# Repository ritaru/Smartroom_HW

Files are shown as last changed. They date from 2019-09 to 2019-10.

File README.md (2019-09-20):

# ATmega256RFR2 Zigbee Board & Firmware

## Development board specs

- 50mm x 50mm 1.6T FR-4 1oz Copper
- microUSB port for power input
- Integrated 3.3v regulator(IL1117-3.3)
- Overcurrent and overvoltage protection(PTC, TVS diode)
- GPIOs are populated by port indexes
- ISP Connector(10-pin) for programming
- ATmega64/128/256RFR2 compatible
- All resistors, inductors, capacitors are 0603(1608 Metric) size.
- Antenna is connected to u.FL(IPEX) external connector
- The schematic is mostly like the datasheet's application note example.

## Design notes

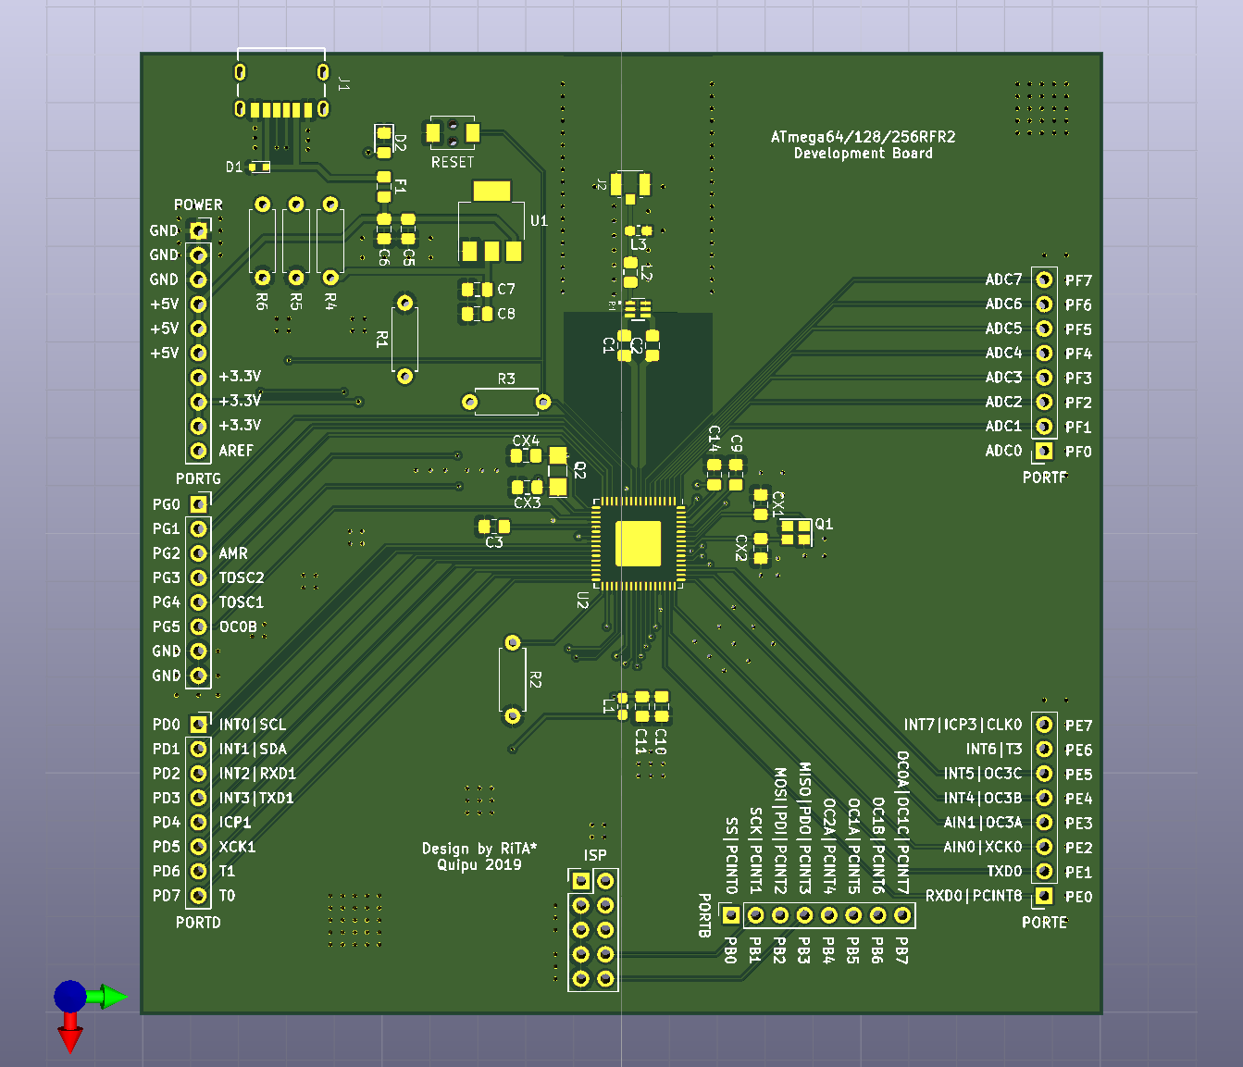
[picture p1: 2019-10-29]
PCB/Dev_Board/board.png

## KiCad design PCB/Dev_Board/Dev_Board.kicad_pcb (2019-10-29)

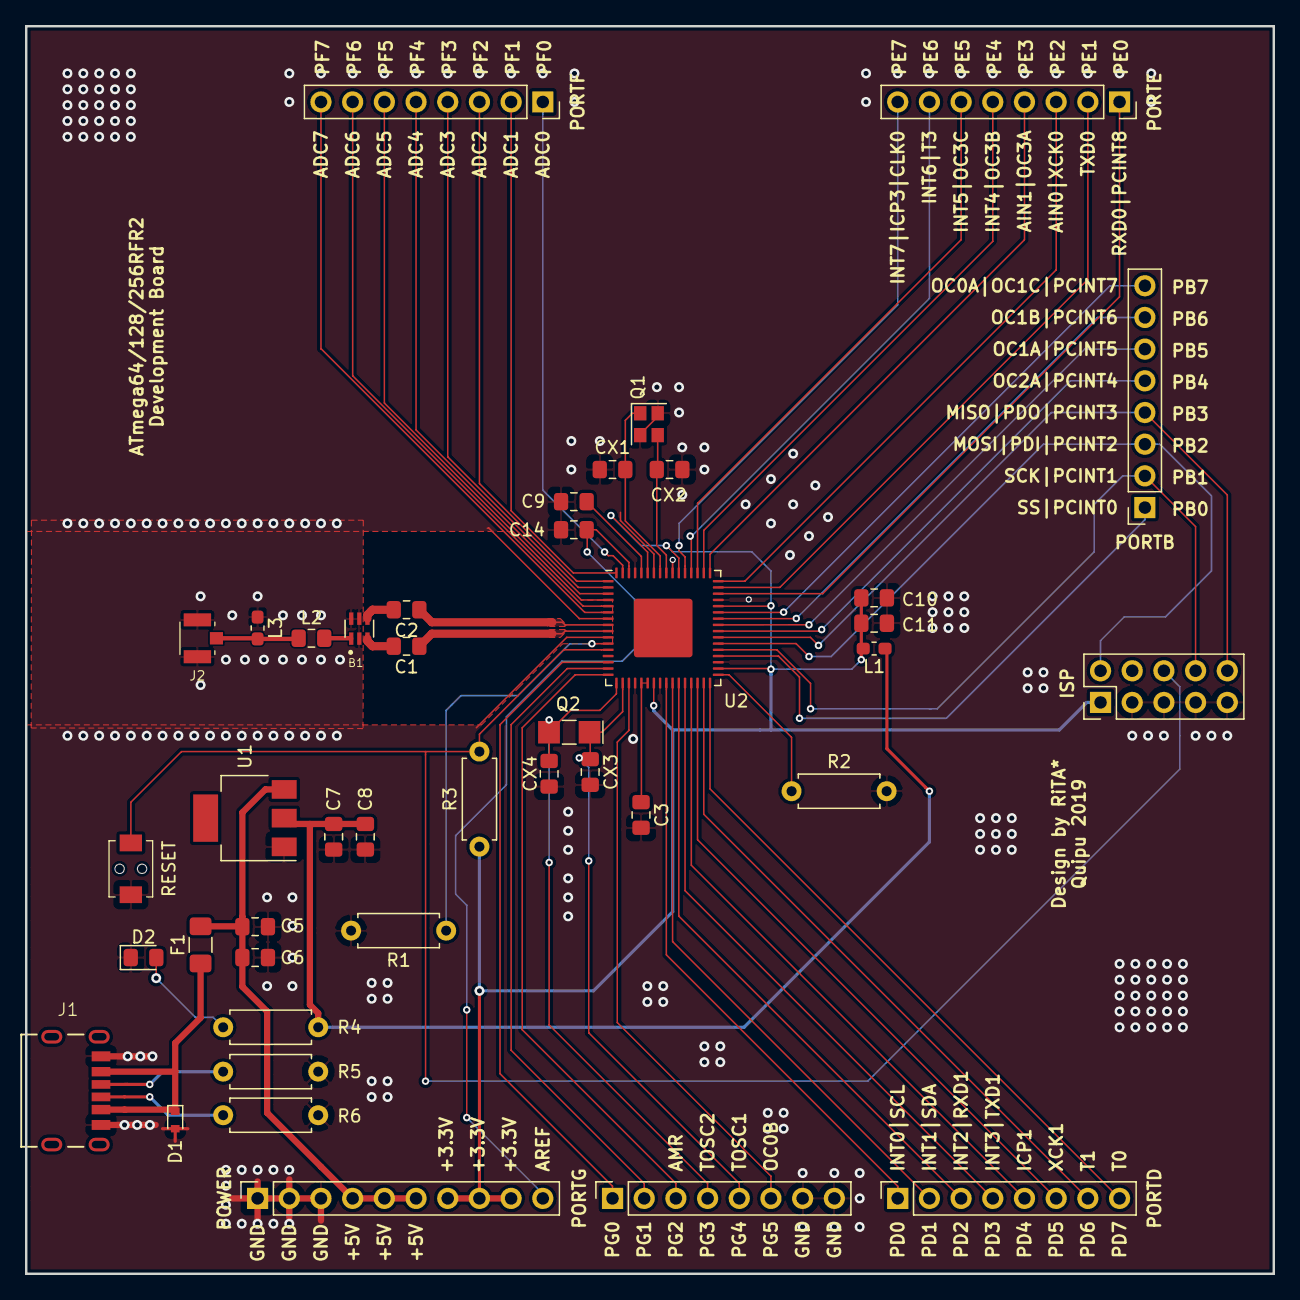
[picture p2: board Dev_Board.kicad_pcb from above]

Board: 2 copper layers, 100.0 x 100.0 mm, 42 parts (0 on the bottom side), 60 nets.

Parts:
B1: BALUN0805; 2450BM15A0015E
C1, C2: 22p; C_0805_2012Metric_Pad1.15x1.40mm_HandSolder
C3, C9: 1u; C_0805_2012Metric_Pad1.15x1.40mm_HandSolder
C5, C7: 4.7u; C_0805_2012Metric_Pad1.15x1.40mm_HandSolder
C6, C8, C10, C11, C14: 100n; C_0805_2012Metric_Pad1.15x1.40mm_HandSolder
CX1, CX2, CX3, CX4: 12p; C_0805_2012Metric_Pad1.15x1.40mm_HandSolder
D1: CESD5V0D5; D_SOD-523
D2: E6C0603URAC1UDA; LED_0805_2012Metric_Pad1.15x1.40mm_HandSolder
F1: MF-NSMF110-2; Fuse_1206_3216Metric_Pad1.42x1.75mm_HandSolder
ISP1: Conn_02x05_Odd_Even; PinHeader_2x05_P2.54mm_Vertical
J1: TYPE-C-31-M-17
J2: Conn_Coaxial; U.FL
L1: BLM18BB221SN1D; L_0603_1608Metric_Pad1.05x0.95mm_HandSolder
L2: Balancing; L_0805_2012Metric_Pad1.15x1.40mm_HandSolder
L3: Balancing; L_0603_1608Metric_Pad1.05x0.95mm_HandSolder
PORTB1: Conn_01x08; PinSocket_1x08_P2.54mm_Vertical
PORTD1: Conn_01x08; PinSocket_1x08_P2.54mm_Vertical
PORTE1: Conn_01x08; PinSocket_1x08_P2.54mm_Vertical
PORTF1: Conn_01x08; PinSocket_1x08_P2.54mm_Vertical
PORTG1: Conn_01x08; PinSocket_1x08_P2.54mm_Vertical
POWER1: Conn_01x10; PinSocket_1x10_P2.54mm_Vertical
Q1: 16M; Crystal_SMD_2520-4Pin_2.5x2.0mm
Q2: 32.768k; Crystal_SMD_EuroQuartz_EQ161-2Pin_3.2x1.5mm_HandSoldering
R1, R2: 10k; R_Axial_DIN0207_L6.3mm_D2.5mm_P7.62mm_Horizontal
R3: 100k; R_Axial_DIN0207_L6.3mm_D2.5mm_P7.62mm_Horizontal
R4: 56R; R_Axial_DIN0207_L6.3mm_D2.5mm_P7.62mm_Horizontal
R5, R6: 5.1k; R_Axial_DIN0207_L6.3mm_D2.5mm_P7.62mm_Horizontal
SW1: K2-1807SA-B4DW-06
U1: AMS1117-3.3; SOT-223-3_TabPin2
U2: ATmega256RFR2; QFN-64-1EP_9x9mm_P0.5mm_EP4.7x4.7mm

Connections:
+3V3: C10.1, C11.1, ISP1.1, L1.2, POWER1.7, POWER1.8, POWER1.9, R3.1, U2.23, U2.34, U2.44, U2.54, U2.59
+5V: D1.1, F1.1, J1.VBUS
+VDC: C5.1, C6.1, F1.2, POWER1.4, POWER1.5, POWER1.6, U1.3
AREF: C14.1, POWER1.10, U2.62
GND: B1.GND, C3.2, C5.2, C6.2, C7.2, C8.2, C9.2, C10.2, C11.2, C14.2, CX1.2, CX2.2, CX3.2, CX4.2, D1.2, D2.1, ISP1.3, ISP1.5, ISP1.7, ISP1.9, J1.GND, J2.2, L3.1, PORTG1.7, PORTG1.8, POWER1.1, POWER1.2, POWER1.3, Q1.2, Q1.4, R1.2, R2.2, R5.1, R6.1, SW1.2, U1.1, U2.7, U2.10, U2.20, U2.24, U2.35, U2.45, U2.55, U2.58, U2.61
MISO: ISP1.10, PORTB1.4, U2.39
MOSI: ISP1.2, PORTB1.3, U2.38
unnamed: B1.BAL1, C1.2
unnamed: B1.BAL2, C2.2
unnamed: B1.UNBAL, L2.2
unnamed: C3.1, U2.21, U2.22
unnamed: C7.1, C8.1, L1.1, R4.1, U1.2
unnamed: C9.1, U2.60
unnamed: D2.2, R4.2
unnamed: J1.CC1, R5.2
unnamed: J1.CC2, R6.2
unnamed: J2.1, L2.1, L3.2
unnamed: PORTB1.1, U2.36
unnamed: PORTB1.5, U2.40
unnamed: PORTB1.6, U2.41
unnamed: PORTB1.7, U2.42
unnamed: PORTB1.8, U2.43
unnamed: PORTD1.1, U2.25
unnamed: PORTD1.2, U2.26
unnamed: PORTD1.3, U2.27
unnamed: PORTD1.4, U2.28
unnamed: PORTD1.5, U2.29
unnamed: PORTD1.6, U2.30
unnamed: PORTD1.7, U2.31
unnamed: PORTD1.8, U2.32
unnamed: PORTE1.1, U2.46
unnamed: PORTE1.2, U2.47
unnamed: PORTE1.3, U2.48
unnamed: PORTE1.4, U2.49
unnamed: PORTE1.5, U2.50
unnamed: PORTE1.6, U2.51
unnamed: PORTE1.7, U2.52
unnamed: PORTE1.8, U2.53
unnamed: PORTF1.1, U2.63
unnamed: PORTF1.2, U2.64
unnamed: PORTF1.3, U2.1
unnamed: PORTF1.4, U2.2
unnamed: PORTF1.5, U2.3
unnamed: PORTF1.6, U2.4
unnamed: PORTF1.7, U2.5
unnamed: PORTF1.8, U2.6
unnamed: PORTG1.1, U2.14
unnamed: PORTG1.2, U2.15
unnamed: PORTG1.3, U2.16
unnamed: PORTG1.6, U2.19
unnamed: R1.1, U2.11
unnamed: R2.1, U2.33
RF_N: C1.1, U2.9
RF_P: C2.1, U2.8
SCK: ISP1.8, PORTB1.2, U2.37
TOSC1: CX3.1, PORTG1.5, Q2.1, U2.18
TOSC2: CX4.1, PORTG1.4, Q2.2, U2.17
XTAL1: CX1.1, Q1.1, U2.57
XTAL2: CX2.1, Q1.3, U2.56
~RST: ISP1.6, R3.2, SW1.1, U2.12

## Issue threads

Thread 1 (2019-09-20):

L1 is on the wrong power net.

ritaru, 2019-09-20:
It should be connected after LDO's output filter caps, to ensure that MCU is not affected by the noise.

ritaru, 2019-09-20:
Done.

Closed 2019-09-20.

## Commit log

2019-09-20 Fixed L1 power net
    Also added a power indicator LED
    [Dev_Board.kicad_pcb, Dev_Board.sch]
2019-10-29 Board design almost done
    some parts need to be replaced with larger footprints(fuse, caps, etc...)
    I haven't done the RF side yet.
    Also, I changed the switch to similarly designed one that had more detailed dimensions.
    [Dev_Board.kicad_pcb, Dev_Board.sch]
2019-10-29 Final PCB design
    [Dev_Board.kicad_pcb, Dev_Board.sch]
